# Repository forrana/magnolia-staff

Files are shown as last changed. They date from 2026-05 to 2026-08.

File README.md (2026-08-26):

# Motivation
Fire spinning and flow arts have been my hobbies for a decade now.
Earning money was never a goal for me in this area.
If you check the market, practice and LED equipment, like staffs, are expensive, and at times, fragile.
The goal of this project is to allow hobbyists, like myself, to make their own good-looking practice (and why not) performance equipment.
Equipment they can make, repair, and customize from the comfort of their own kitchens.
Using components they can easily find locally or make themselves at home or at a makerspace.

# Printing Settings
* No supports.
* Print as placed in STL.
* 20% Infill, 4 perimiters, 5 top and bottom solid layers.
* Beam, Front End Disk and Riser Ring parts designed to be printed from TPU or other soft material.
* Back End and Front End parts designed to be printed from hard materials (Tested with silk PLA).

# Navigation

```
magnolia-staff/
├── README.md                    # Project overview and documentation
├── LICENSE.md                   # License information
│
├── files/                       # All project files and assets
│   ├── Blender/                 # Blender 3D model files
│   │   ├── CompleteAssembly.blend        # Full staff assembly
│   │   ├── InnerAssembly.blend           # Inner assembly
│   │   └── OuterEndAssembly.blend        # OuterEndAssembly assembly
│   │
│   ├── CAD/                     # CAD models and designs
│   │   ├── FreeCAD/             # FreeCAD design files (.FCStd)
│   │   │   ├── Assembly/                # Assembled designs
│   │   │   │   └── a2plusassembly.FCStd   # Complete assembly
│   │   │   ├── beam24.FCStd                 # Beam component design
│   │   │   ├── front-disk.FCStd             # Front disk design
│   │   │   ├── front-disk-L.FCStd           # Front disk (Large variant)
│   │   │   ├── front-disk-M.FCStd           # Front disk (Medium variant)
│   │   │   ├── front-end-base-18mm.FCStd    # Front end base (18mm variant)
│   │   │   ├── front-end-base-balance.FCStd # Front end base (balanced variant)
│   │   │   ├── front-end-base-mounting-ring.FCStd
│   │   │   ├── front-end-base.FCStd         # Front end base (standard)
│   │   │   ├── rear-end-18mm.FCStd          # Rear end (18mm variant)
│   │   │   ├── rear-end.FCStd               # Rear end (standard)
│   │   │   ├── riser-ring-18mm.FCStd        # Optional. Rise beams and changes shape of heads (18mm)
│   │   │   ├── riser-ring.FCStd             # Optional. Rise beams and changes shape of heads
│   │   │   └── Tube.FCStd                   # Tube component
│   │   │
│   │   └── STEP/                # STEP files (.step)
│   │       ├── beam24.step                  # Beam component design
│   │       ├── front-disk.step              # Front disk design
│   │       ├── front-end-base-18mm.step     # Front end base (18mm variant)
│   │       ├── front-end-base.step          # Front end base (standard)
│   │       ├── rear-end-18mm.step           # Rear end (18mm variant)
│   │       ├── rear-end.step                # Rear end (standard)
│   │       ├── riser-ring-18mm.step         # Optional. Rise beams and changes shape of heads (18mm)
│   │       └── riser-ring.step              # Optional. Rise beams and changes shape of heads
│   │
│   └── STLs/                    # 3D printable models (STL format)
│       ├── Beams/                # Beam component STL files
│       │   ├── beam24-Beam_Crystal_amp0p50.stl
│       │   └── beam24-Beam.stl
│       │
│       ├── FrontEnd/              # Front end component STL files
│       │   ├── front-disk.stl
│       │   ├── front-end-base-mounting-ring.stl
│       │   └── front-end-base.stl
│       │
│       ├── RearEnd/               # Rear end component STL files
│       │   └── rear-end.stl
│       │
│       └── Optional/              # Optional component STL files
│           ├── front-disk-L.stl
│           ├── front-disk-M.stl
│           ├── front-end-base-balance.stl
│           └── riser-ring.stl
│
└── manual/                      # User documentation
    ├── animations/               # Assembly animation files
    │   ├── part1/                # Part 1 animations
    │   ├── part2/                # Part 2 animations
    │   └── part3/                # Part 3 animations
    ├── manual.md                # Detailed assembly and usage guide
    └── images/                  # Screenshots and reference images
```

**Quick Links:**
- 🎨 **Blender Models**: Check [files/Blender/](./files/Blender/) for Blender assembly files
- 📋 **FreeCAD Models**: Check [files/CAD/FreeCAD/](./files/CAD/FreeCAD/) for FreeCAD designs
- 📋 **CAD STEP Models**: Check [files/CAD/STEP/](./files/CAD/STEP/) for universal STEP designs
- 🖨️ **3D Print Files**: Find ready-to-print models in [files/STLs/](./files/STLs/)
- 📖 **Assembly Guide**: See [manual/manual.md](./manual/manual.md) for building instructions
- **Printables page**: [Project page](https://www.printables.com/model/1709430-magnolia-practice-flow-spinning-staff)

# Ways to contribute
Let's figure it out together if this project develops further!
For now:
* Clone the project
* Create a branch
* Make your changes
* Open a PR

For ideas and discussion just open an issue in the github tracker

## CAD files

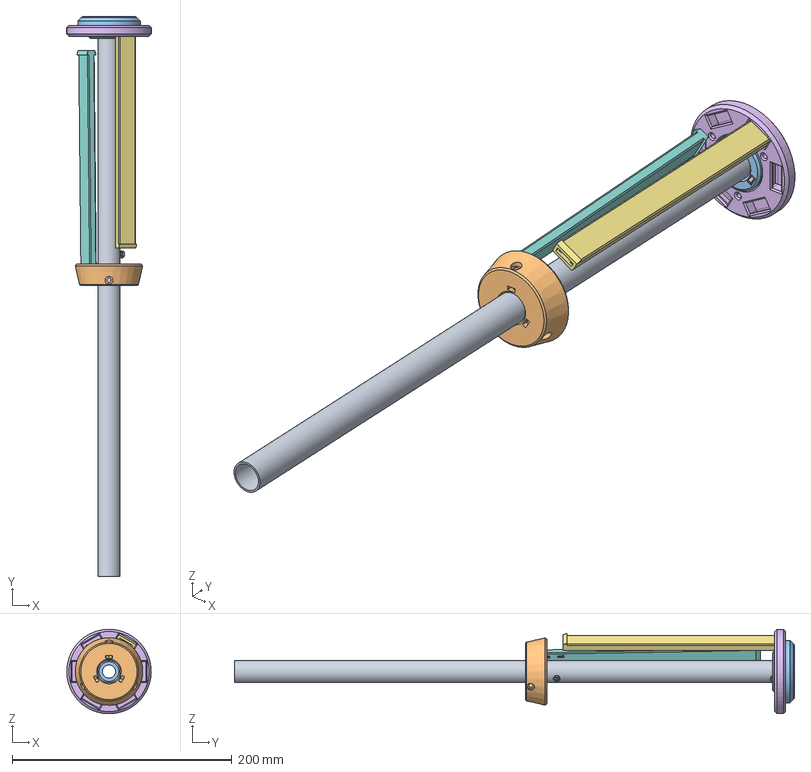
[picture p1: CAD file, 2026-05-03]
files/CAD/FreeCAD/Assembly/a2plusassembly.FCStd
77.0 x 510.0 x 76.9 mm
pipe_001
rear-end_001
front-end-base_001
ISO4032_Hex_Nut_M3_001
ISO4032_Hex_Nut_M3_002
front-disk_001
beam24_001
beam24_002

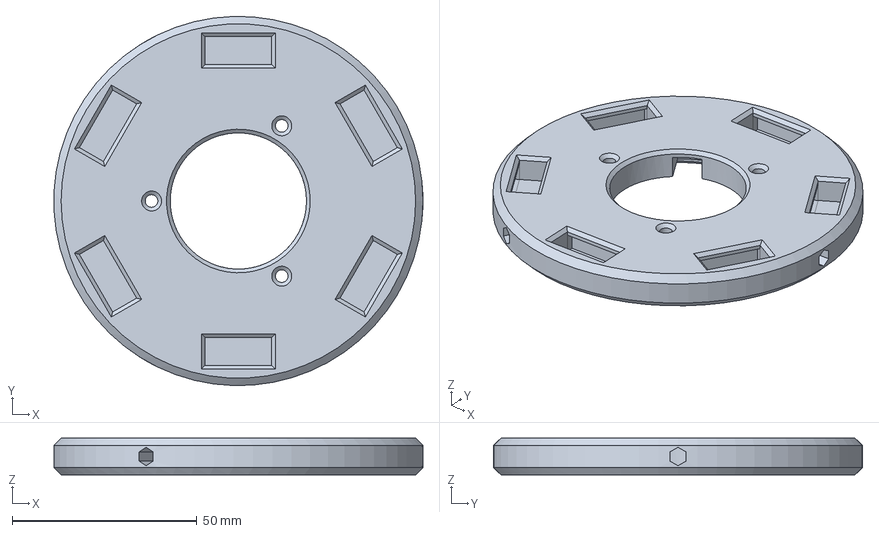
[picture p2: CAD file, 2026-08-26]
files/CAD/FreeCAD/front-disk-L.FCStd
99.9 x 100.0 x 10.0 mm

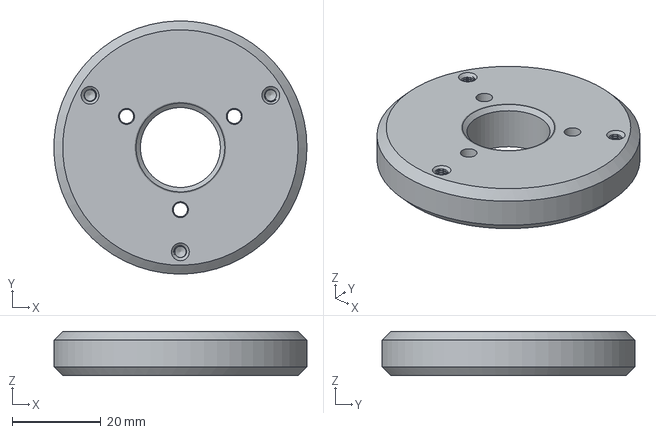
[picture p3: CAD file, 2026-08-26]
files/CAD/STEP/front-end-base.step
57.0 x 57.0 x 10.0 mm

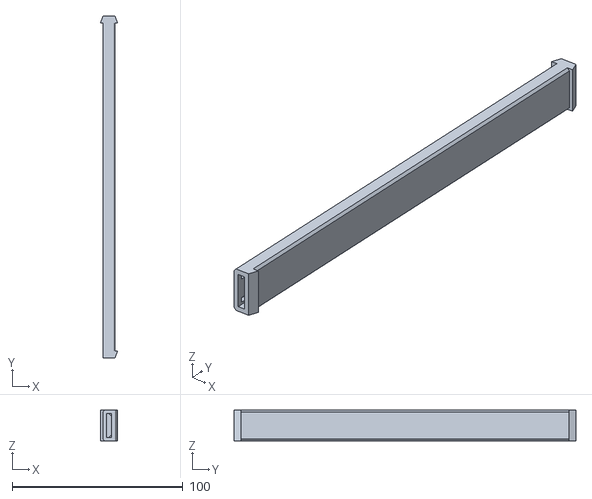
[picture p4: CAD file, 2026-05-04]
files/STLs/Beams/beam24-Beam.stl
10.0 x 200.0 x 18.0

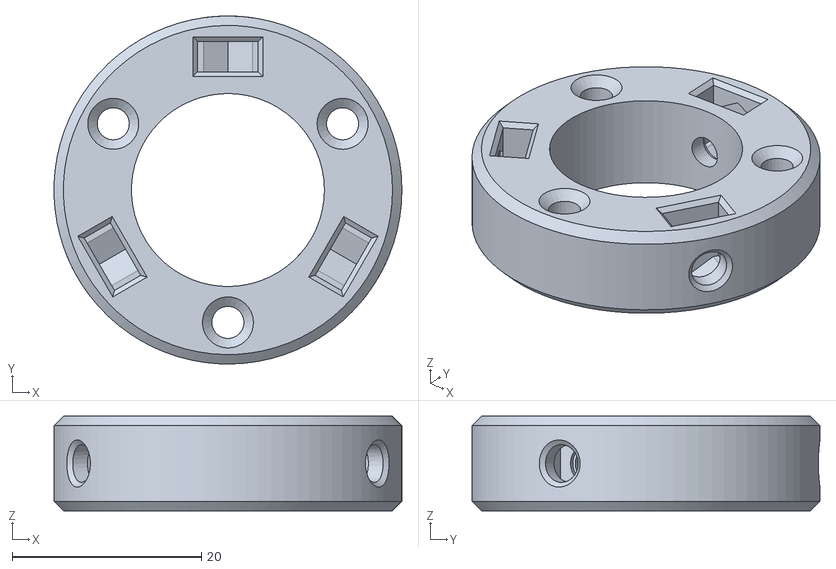
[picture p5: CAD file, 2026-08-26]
files/STLs/FrontEnd/front-end-base-mounting-ring.stl
36.8 x 36.8 x 10.0

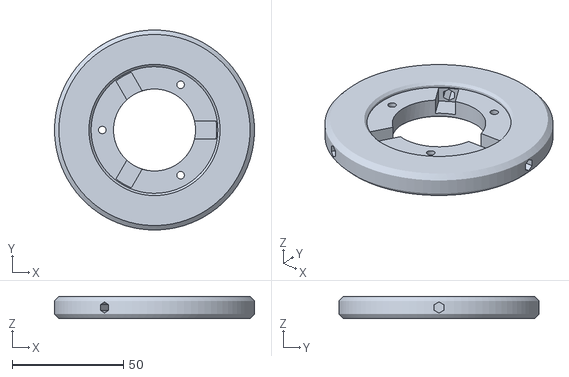
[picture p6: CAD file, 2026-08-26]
files/STLs/Optional/front-disk-M.stl
90.0 x 90.0 x 10.0

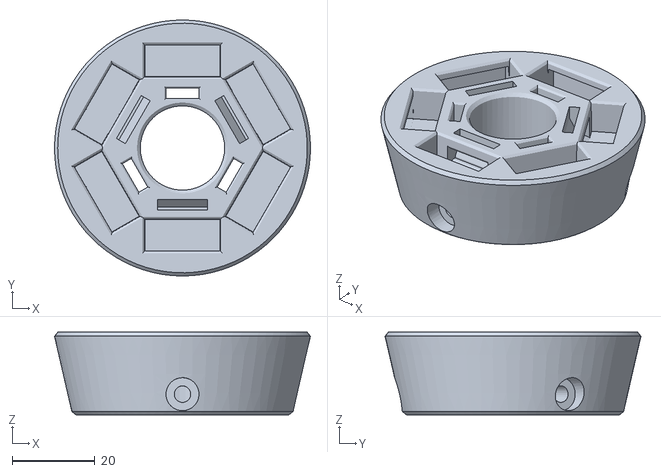
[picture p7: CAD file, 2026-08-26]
files/STLs/RearEnd/rear-end.stl
62.0 x 62.0 x 20.0

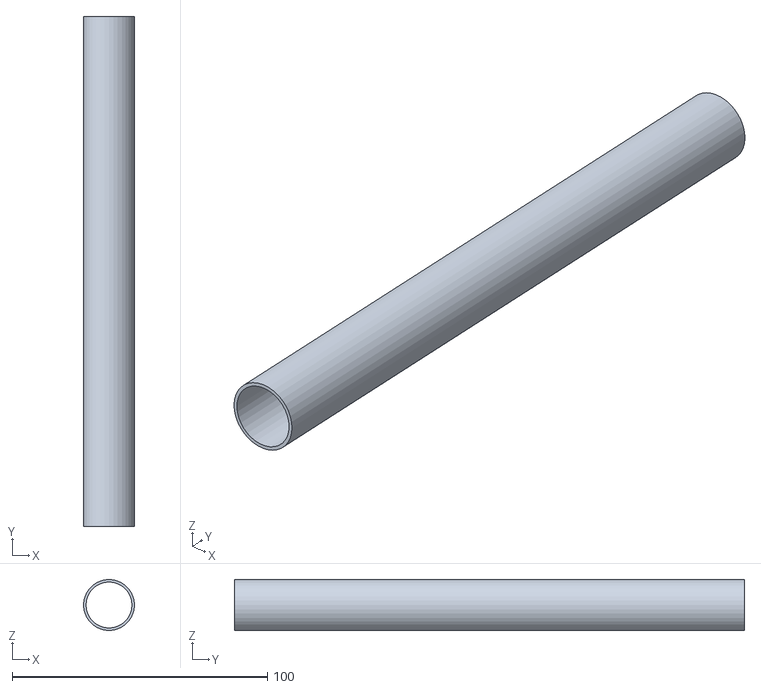
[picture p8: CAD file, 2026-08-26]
files/CAD/FreeCAD/tube-20mm.stl
20.0 x 200.0 x 20.0

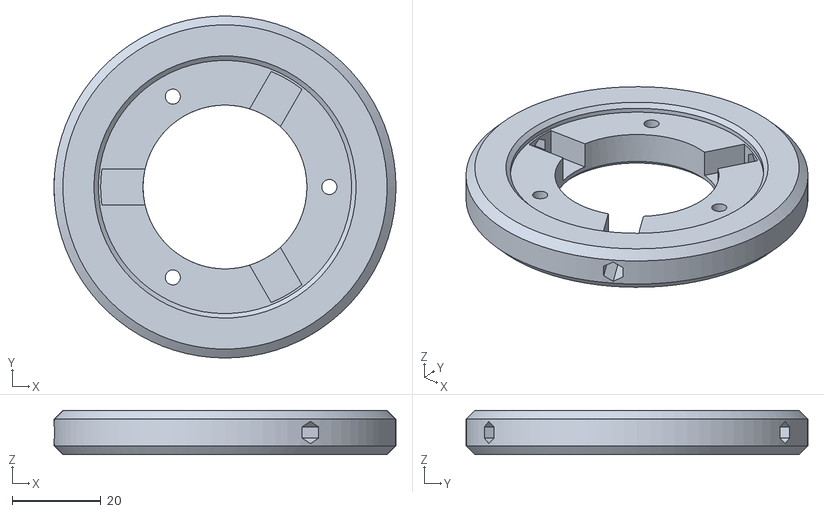
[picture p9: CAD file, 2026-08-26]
files/STLs/FrontEnd/front-disk.stl
77.0 x 77.0 x 10.0

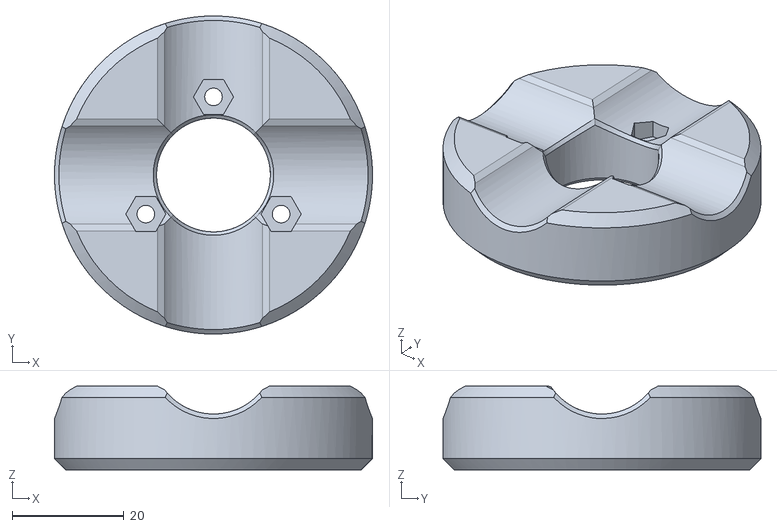
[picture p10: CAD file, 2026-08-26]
files/STLs/Optional/front-end-base-balance.stl
57.0 x 57.0 x 15.0

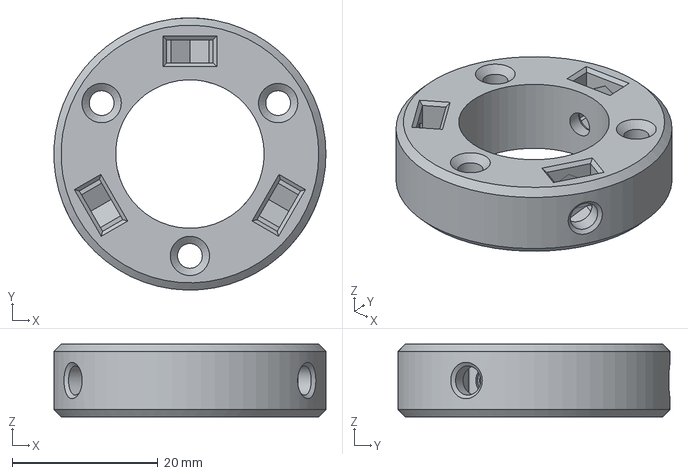
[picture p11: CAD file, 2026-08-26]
files/CAD/STEP/front-end-base-mounting-ring.step
37.4 x 37.4 x 10.0 mm

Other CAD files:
files/CAD/STEP/rear-end.step
files/STLs/Beams/beam24-Beam_Crystal_amp0p50.stl
files/CAD/FreeCAD/Tube.FCStd
files/STLs/FrontEnd/front-end-base.stl
files/STLs/Optional/front-disk-L.stl
files/CAD/FreeCAD/front-end-base-balance.FCStd
files/CAD/STEP/front-disk.step
files/Blender/CompleteAssembly.blend
files/Blender/InnerAssembly.blend
files/Blender/OuterEndAssembly.blend
files/CAD/FreeCAD/beam24.FCStd
files/CAD/FreeCAD/front-disk-M.FCStd
files/CAD/FreeCAD/front-disk.FCStd
files/CAD/FreeCAD/front-end-base-18mm.FCStd
files/CAD/FreeCAD/front-end-base-mounting-ring.FCStd
files/CAD/FreeCAD/front-end-base.FCStd
files/CAD/FreeCAD/rear-end-18mm.FCStd
files/CAD/FreeCAD/rear-end.FCStd
files/CAD/FreeCAD/riser-ring-18mm.FCStd
files/CAD/FreeCAD/riser-ring.FCStd
files/CAD/STEP/beam24.step
files/CAD/STEP/front-end-base-18mm.step
files/CAD/STEP/riser-ring-18mm.step
files/CAD/STEP/riser-ring.step
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

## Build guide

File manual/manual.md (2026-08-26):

# Bill of materials per staff 
## Hardware
| Part | Per side | Total | Notes |
|---|---|---|---|
| BHCS M3x12mm | 3 | 6 | Front Base to Front End Disk (Optional) |
| SHCS M3x16mm | 3 | 6 | Rear End mounting |
| SHCS M3x20mm | 3 | 6 | Front Base to Mounting Ring |
| SHCS M3x10mm | 3 | 6 | Mounting Ring |
| M3 nuts | 9 | 18  |
| M3 spacers | 6 | 12  |
| M3 grovers | 6 | 12  | 

You'll need an Aluminium or Carbon tube as well if you make it from the scratch.
Try to find one with thicker walls, 1-1.5mm thick walls bend quite easily.
At least 2mm is required to be able to take some hits.
Currently supported tubes are with 20mm outer diameters.

## 3d printed parts
### Printing instructions
* No supports.
* Print as placed in STL.
* 20% Infill, 4 perimiters, 5 top and bottom solid layers.
* Beam and Front End Disk designed to be printed from TPU or other soft material.
* Back End and Front End parts designed to be printed from hard materials (Tested with silk PLA).

### 20mm base tube diameter
| Part | Material  | Quantity  | Link |
|---|:---:|:---:|:---|
| Front End Ring | PLA | 2 | [front-end-mounting-ring.stl](../files/STLs/FrontEnd/front-end-base-mounting-ring.stl) |
| Front End Base | TPU | 2 | [front-end-base.stl](../files/STLs/FrontEnd/front-end-base.stl) |
| Front End Disk | TPU | 2 | [front-disk.stl](../files/STLs/FrontEnd/front-disk.stl) |
| Rear end | PLA | 2 | [rear-end.stl](../files/STLs/RearEnd/rear-end.stl) |
| Beam | TPU | 6(12)  | [beam24-Beam.stl](../files/STLs/Beams/beam24-Beam.stl) |

### Optional modifications
#### Bigger diameters of front disk if you wanna make a slower version
* [front-disk-L.stl](../files/STLs/Optional/front-disk-L.stl)
* [front-disk-M.stl](../files/STLs/Optional/front-disk-M.stl)

#### Thicker Front End Base part with groves of the diameter of the staff
* [front-end-base-balance.stl](../files/STLs/Optional/front-end-base-balance.stl)

#### Riser ring you can put into assembled part to change its shape
* [riser-ring.stl](../files/STLs/Optional/riser-ring.stl)

# Assembly instructions

## Front End assembly
1. Preload nuts into **Front End Ring** part
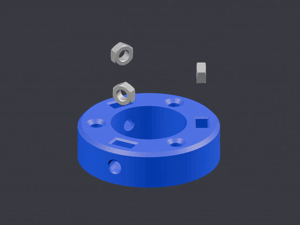
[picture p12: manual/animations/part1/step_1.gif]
   * 
2. Prepare **M3x10** mounting bolts. Put grover first and then spacer
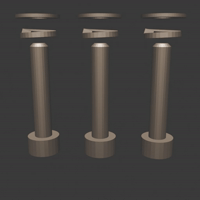
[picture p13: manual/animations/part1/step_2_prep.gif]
Prepare bolts
   * 
3. Preload prepared **M3x10** bolts into **Mounting Ring**
   * NOTE! They should not protrude!
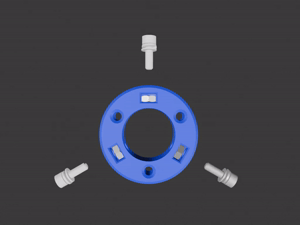
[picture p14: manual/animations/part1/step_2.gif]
Preload bolts
   * 
4. Put **Mounting Ring** into **Front End Disk**
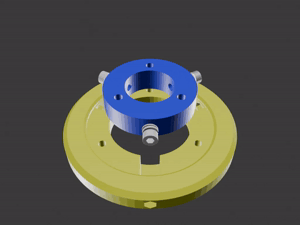
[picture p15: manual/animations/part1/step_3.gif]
   * 
5. Preload **M3x20** bolts into **Front End Disk** 
   * NOTE! They should only sligtly protrude from the other side!
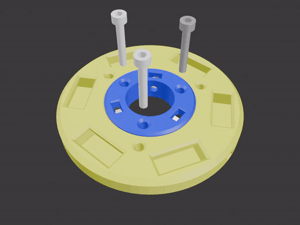
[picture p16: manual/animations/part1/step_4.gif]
   * 
6. Preload **M3 nuts** into **Front End Base**
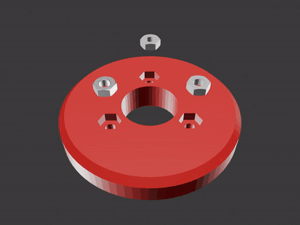
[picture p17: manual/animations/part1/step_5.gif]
   * 
7. Put **Front End Base** on **Front End Disk**
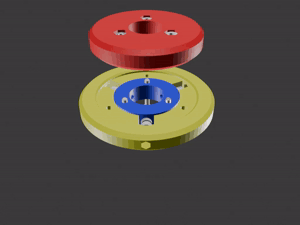
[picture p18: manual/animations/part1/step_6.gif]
Connect base with disk
   * 
8. Now time to tighten the bolts!
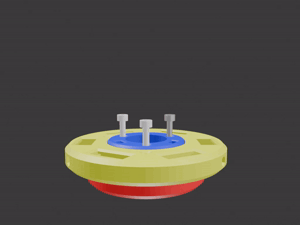
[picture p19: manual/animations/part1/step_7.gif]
Tighten bolts
    *  

## Rear End assembly
1. Preload nuts into **Rear End**
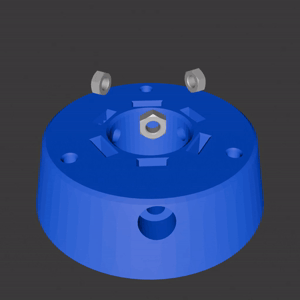
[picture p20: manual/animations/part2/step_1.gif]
   * 
2. Prepare **M3x16** mounting bolts. Put grover first and then spacer
   * Prepare bolts
3. Preload **M3x16** bolts into **Rear End** 
   * NOTE! They should not protrude!
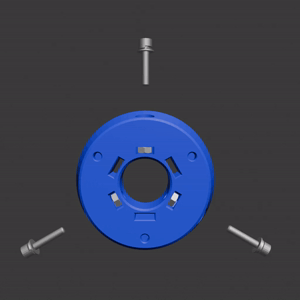
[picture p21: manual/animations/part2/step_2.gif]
   * 

## Let's join parts together!
1. Now it's time to attach **Beams** to the **Front End Disk**.
   * Note the squere holes on the end with one fin should look inside!
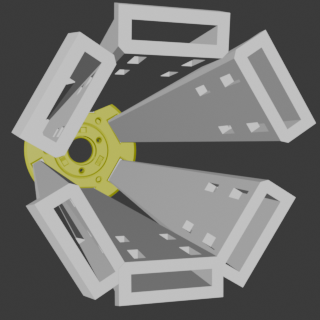
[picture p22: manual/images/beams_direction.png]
Beams orientation
   * 
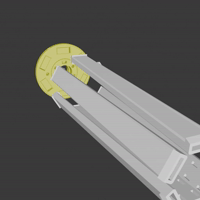
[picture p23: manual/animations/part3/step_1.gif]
Attach Beams
   * 

## Step 4
1. Now let's attach the other end of the **Beams** to the **Rear End**
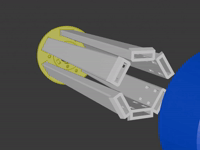
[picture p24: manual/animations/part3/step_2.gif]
Step 4 assembled
   * 

## Step 5
1. Now it's time to put complete assembly on the aluminium tube.
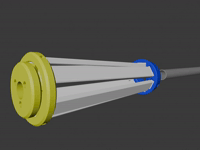
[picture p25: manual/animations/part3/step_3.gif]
Step 5 assembled
   * 

## Step 6
1. Don't forget to tighten now the assembled part on the tube by screwing screws fully on the
   1. **Rear End**
   2. **Front End Mounting Ring** through the holes in the **Front End Disk**

## Final
Good job! It's done!
Now repeat the same steps for the other end of the staff and enjoy the flow!
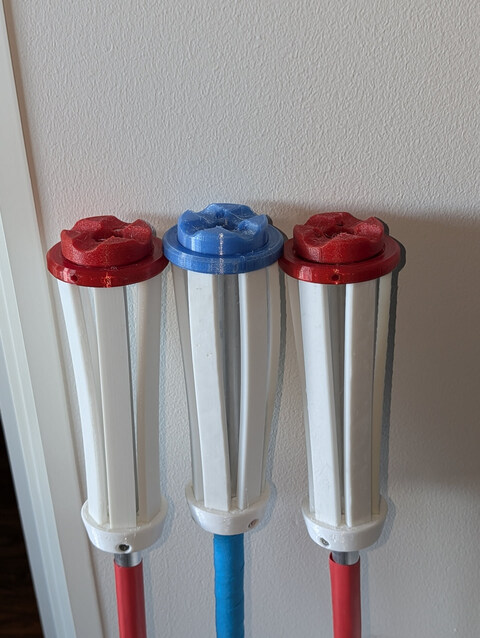
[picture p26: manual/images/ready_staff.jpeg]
Ready staff


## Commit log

2026-05-03 feat: add initial 3d models files * files/CAD contains all FreeCAD files (STEP will follow later) * files/STLs has common 20mm and 18mm folder ** common folder has files that are base tube diameter a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
    [a2plusassembly.FCStd, beam24-Beam.stl, beam24-Beam_Crystal_amp0p50.stl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]
2026-05-03 feat: add assembly instructions * manual folder contains images and manual.md file that has assembly instructions of the staff
2026-05-04 other: update manual.md file with links and printing settings
2026-05-04 other: place parts the way they should be printed
    [beam24-Beam.stl, front-disk.stl, rear-end-18mm.stl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]
2026-05-04 feat: update README.md file with printing setting, and link to the project
2026-05-05 refactor: redesign models to have base hole last in the tree
    * Redesign models so that the base hole that might need to be adjusted
    the most, placed the last in the tree and doesn't require all model
    recomputing on change
    * Export STEP files for all models to allow edit them in different CADs
    * Update README.md with new STEP folder, minor text adjustments there as
    well
    [beam24.FCStd, beam24.step, front-disk.FCStd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]
2026-05-13 other: resave freecad files after recomputing with Freecad 1.1.1
    [beam24.FCStd, front-disk.FCStd, front-end-base-18mm.FCStd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]
2026-05-13 fix: fix broken CAD files. Looks like there were issue with saving some files
    [front-disk.FCStd, front-end-base.step]
2026-05-13 feat: add optional riser ring that can be dropped into assembled staff head and change its shape
    [riser-ring-18mm.FCStd, riser-ring-18mm.step, riser-ring-18mm.stl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]
2026-05-26 fix: make outer diameter for inner ring 1mm bigger
    I've noticed that 10mm doesn't fit well to a current 20mm front-end-base
    there at least 1 extra mm
    Increased diameter to 1mm meaning there will
    be 0.5mm bigger distance on the side.
    In theory that should help to center it better now it plays a bit
    because thread is too long.
    [front-end-base.FCStd, front-end-base.step, front-end-base.stl]
2026-05-29 fix: adjust fitting diameter for front-disk according with recent changes in front-end-base diameter change
    In the previous commit we changed front-end-base inside tube diameter
    Front-disk fitting surface is attaching to this diameter, forgot to
    adjust it accordingly
    [front-disk.FCStd, front-disk.step, front-disk.stl]
2026-08-26 feat: Complete upgrade of all components, major manual update
    * After field tests some weak spots in existing part were spotted
    As a result every part was changed, some have bigger changes, other
    smaller
    ** Rear End part
    *** Attachment holes widened to fit spacer and grower
    *** Bottom part of beam attachment cut is reinforced
    *** Added channels for future wires
    ** Front Disk
    *** Holes on top of bolts added to allow to adjust tention without
    disassembly
    ** Front End Base split into Mounting Ring part and TPU Base part
    *** Mounting Ring part adjusted to fit grower and spacer
    * Manual updates
    ** All photos replaced by blender animations
    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
    [CompleteAssembly.blend, InnerAssembly.blend, OuterEndAssemly.blend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]
2026-08-26 other: re-export changed step and stl files, update README
    [OuterEndAssembly.blend, OuterEndAssemly.blend, front-disk-L.stl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]
2026-08-26 other: remove file accidentally added by resolving merge conflict
    [front-disk.stl]
